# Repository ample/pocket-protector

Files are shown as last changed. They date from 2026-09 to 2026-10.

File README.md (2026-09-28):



Pocket Protector is a privacy-first DIY push-button voice recorder with searchable, fully local memory. Press a button to record, and the audio is transcribed, indexed, and made queryable with a local LLM. Nothing leaves your network.

```
[Button] → ESP32-C3 → Raspberry Pi (records chunks) → recordings/<session>/ on Mac
                                                          │
                                   processor.py (polls every 5s)
                                   1. ffmpeg: concat + loudnorm → session.wav
                                   2. Whisper (MLX) + pyannote speakers → transcript.txt + segments.json
                                   3. Ollama embeddings → Chroma vector DB
                                                          │
                          ask.py "question" → top-6 retrieval → llama3.1:8b answer with citations
```

## Repo layout

The repo is organized by where the code runs.

| Directory | Runs on | What it does |
|---|---|---|
| [`controller/`](controller/) | ESP32-C3 | Button gestures, record/shutdown pulses to the Pi, PowerBoost power control |
| [`pi/`](pi/) | Raspberry Pi | Records chunked audio sessions and syncs them to the Mac |
| [`mac/`](mac/) | Mac (Apple Silicon) | Transcribes, indexes, and answers questions |
| [`hardware/`](hardware/) | 3D printer | Enclosure files and parts list |
| [`site/`](site/) | Any static host | Setup microsite: a step-by-step build guide |

Each directory has its own README with setup steps.

## Session format (Pi → Mac contract)

```
recordings/YYYYMMDD-HHMMSS/
├── chunk-HHMMSS-NN.wav   # ~1-minute chunks, written by the Pi
├── DONE                  # Pi: recording finished and synced
├── session.wav           # Mac: concatenated + normalized
├── transcript.txt        # Mac: full text
├── segments.json         # Mac: [{start, end, speaker, text}, ...]
├── TRANSCRIBED           # Mac: stage 1 complete
└── INDEXED               # Mac: stage 2 complete
```

If you change this format on one side, update the other.

## Privacy

`recordings/` and `chroma/` (which stores transcript text) are git-ignored and never committed. So are `.env` files. Put hostnames and credentials there, and commit only the `.env.example` templates.

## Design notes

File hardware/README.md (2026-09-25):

# Hardware

3D-printable parts, exported from Fusion as `.3mf`.

| File | Purpose |
|---|---|
| `enclosure.3mf` | Main enclosure |
| `plug_test.3mf` | Test print for plug fit |

## Parts

- Raspberry Pi (model: TODO)
- ESP32-C3 Super Mini
- PowerBoost board with FM5324HJ1 boost IC + battery
- INMP441 I2S MEMS microphone
- Momentary push button
- 2N2222 NPN transistor + 1 kΩ resistor

See [controller/README.md](../controller/README.md) for wiring.

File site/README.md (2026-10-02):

# Setup microsite

A static, five-page build guide for Pocket Protector: overview, hardware, Raspberry Pi, Mac, and record & ask. Plain HTML, one stylesheet and one small script for the mobile menu, with no build step.

| File | Page |
|---|---|
| `index.html` | Overview and how it works |
| `hardware.html` | 01 · Print, wire, and flash the controller |
| `pi.html` | 02 · Boot config, Tailscale, SSH, services |
| `mac.html` | 03 · Clone, models, pyannote unlock, processor |
| `use.html` | 04 · Gestures, session lifecycle, `ask.py`, troubleshooting |
| `assets/styles.css` | Shared styles and color tokens |
| `assets/nav.js` | Mobile menu toggle (the nav falls back to a scrolling row without it) |
| `assets/logo.png` | Wordmark |
| `assets/og-image.png` | 1200×630 social share image |

## Preview

```bash
python3 -m http.server 8000 --directory site
```

Then open http://localhost:8000.

## Deploy

Any static host works. Point it at `site/` with no build command.

## Keeping it accurate

The pages repeat facts from the device READMEs: pins, pulse timings, paths, and model names. If you change them in `controller/`, `pi/`, or `mac/`, update the matching page too.

Placeholders still to fill in:

- `[PI MODEL]` in `index.html` (the parts list)
- `[ADD MIC PIN MAP]` in `hardware.html` (Pi-side wiring)

## Share previews

Each page has Open Graph and Twitter card tags pointing at `https://pocket-protector.diy`. If the site moves to another domain, update the `canonical`, `og:url`, `og:image` and `twitter:image` URLs in every page.

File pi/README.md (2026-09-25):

# Pi (recorder)

The Raspberry Pi listens for control pulses from the [controller](../controller/), records audio in 1-minute chunks, and uploads finished sessions to the Mac over Tailscale.

## Layout

| Path | Contents |
|---|---|
| `recorder.py` | GPIO15 pulse listener; runs `arecord` in 1-minute chunks and writes `DONE` |
| `uploader.py` | rsyncs finished sessions to the Mac and writes a local `UPLOADED` marker |
| `systemd/` | Unit templates for both services (`__USER__` etc. are filled in by `install.sh`) |
| `config/config.txt.snippet` | The lines added to `/boot/firmware/config.txt` |
| `config/sudoers.d/recorder-shutdown` | Lets the recorder run `shutdown -h now` without a password |
| `install.sh` | Installs packages, the sudoers rule, and the services |
| `.env.example` | Template for the upload destination; copy to `.env` (git-ignored) |

## Hardware

- **Mic:** INMP441 I2S MEMS mic, driven by the `googlevoicehat-soundcard` overlay. It appears as ALSA card `sndrpigooglevoi`; check with `arecord -l`.
- **Control input:** physical pin 10 (BCM GPIO15), with an internal pull-up, receiving open-drain LOW pulses from the ESP32.
- **Recording LED:** BCM GPIO27.

| Pulse length | Meaning |
|---|---|
| 0.05–0.70 s (ESP32 sends ~150 ms) | Toggle recording |
| ≥0.90 s (ESP32 sends ~1200 ms) | Stop any recording, write `DONE`, then `shutdown -h now`. The ESP32 cuts power 15 s later. |

Pin 10 is also UART RX, which is why `config.txt` sets `enable_uart=0`. `cmdline.txt` must not contain `console=serial0,...`. A stock Bookworm install only uses `console=tty1`.

## Setup

1. **Boot config:** add the lines from [`config/config.txt.snippet`](config/config.txt.snippet) under `[all]` in `/boot/firmware/config.txt`, then reboot.
2. **Tailscale:** install and log in on both the Pi and the Mac.
3. **SSH to the Mac:** the uploader uses `ssh -o BatchMode=yes`, so it needs key auth.
   - On the Mac: System Settings → General → Sharing → turn on **Remote Login**.
   - On the Pi: `ssh-keygen -t ed25519` (if you don't have a key), then `ssh-copy-id <mac-user>@<mac-host>`.
   - Test with `ssh -o BatchMode=yes <mac-user>@<mac-host> true`.
4. **Configure:** `cp pi/.env.example pi/.env` and fill in the Mac user, host, and recordings path.
5. **Install:** from the repo clone on the Pi, run `./pi/install.sh`.

Logs: `journalctl -u recorder -u uploader -f`

## Output contract

Sessions are recorded to `~/recordings/` on the Pi:

```
~/recordings/YYYYMMDD-HHMMSS/   # named by the Pi's clock at record start
├── chunk-HHMMSS-01.wav         # arecord --max-file-time 60, 16 kHz mono S16_LE
├── chunk-HHMMSS-02.wav
├── DONE                        # written after arecord exits
└── UPLOADED                    # Pi-only; written after a successful upload
```

## Sync to the Mac

`uploader.py` polls every 5 s for sessions that have `DONE` but not `UPLOADED`. For each one, it:

1. rsyncs the audio, excluding the `DONE` and `UPLOADED` markers
2. rsyncs `DONE` on its own, **last**

The Mac's [processor](../mac/) therefore never sees `DONE` before all the audio has arrived. Failed uploads retry on the next pass.

## Known limitations

- Uploaded sessions are never deleted from the Pi, so the SD card will fill up over time.
- The Pi has no real-time clock. Sessions recorded before it syncs time over the network can get wrong timestamps in their names.

## Don't commit

SSH keys, Wi-Fi config (`wpa_supplicant.conf`, NetworkManager connections), Tailscale auth, and `pi/.env`.

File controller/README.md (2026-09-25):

# Controller (ESP32-C3)

An always-on ESP32-C3 Super Mini reads one momentary button. It tells the Pi to start or stop recording and to shut down, and it switches the PowerBoost's 5V output on and off.

## Gestures

| Gesture | Action |
|---|---|
| Single click | 150 ms LOW pulse to the Pi: toggle recording |
| Double click | Unused |
| Triple click | Tap the PowerBoost K pin: power the Pi on |
| Long press (≥2.5 s, fires on release) | 1200 ms pulse to the Pi (shutdown), wait 15 s, double-tap K to cut 5V |

The Pi distinguishes record and shutdown requests by pulse length.

## Wiring

| ESP32 pin | Connects to |
|---|---|
| GPIO 4 | Momentary button → GND (internal pull-up) |
| GPIO 5 | 1 kΩ → base of a 2N2222 that pulls the PowerBoost K pin to ground |
| GPIO 3 | Raspberry Pi physical pin 10 (GPIO15), open-drain |
| GND | Common ground |

GPIO 3 is open-drain so the ESP32 never drives voltage into a powered-off Pi. The Pi's pull-up holds the line high.

## Flashing

1. Open `esp32_controller/esp32_controller.ino` in the Arduino IDE. The folder name must match the sketch name.
2. Board: **ESP32C3 Dev Module** (esp32 core by Espressif). Enable *USB CDC On Boot* to get serial output.
3. Upload, then open Serial Monitor at 115200 baud to see gesture logs.

## Timing constants

All timings are `const`s at the top of the sketch: debounce, click window, long-press threshold, K tap/gap, pulse lengths, and the shutdown delay. The K timings match the FM5324HJ1 boost IC. There, one short press is a tap and a double press turns the output off.

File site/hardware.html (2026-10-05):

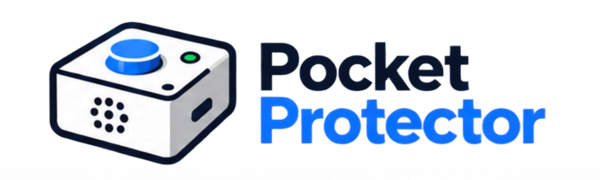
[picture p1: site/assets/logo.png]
Pocket Protector home
 Menu

STEP 01 OF 04

# Build the hardware

Print the case, make three connections to the ESP32, and flash the controller. When you're done, one button powers the Pi on, starts recordings and shuts everything down.

1.1 · PRINT

## Print the enclosure

Both parts are in hardware/, exported from Fusion as .3mf. Start with the small plug test. It tells you if the plug fits before you commit to the full case.

plug_test.3mf

First · checks plug fit

enclosure.3mf

Then · the main case

1.2 · WIRE

## Wire the controller

The ESP32-C3 stays on all the time. It reads the button, signals the Pi, and switches the PowerBoost's 5V output through a 2N2222.

Why open-drain?

GPIO 3 never drives voltage into a powered-off Pi. The Pi's pull-up holds the line high, and the ESP32 only pulls it low.

Power switching

The transistor "presses" the PowerBoost K pin. One tap turns 5V on, a double tap turns it off.

Pi-side wiring

INMP441 mic to the Pi's I2S pins, recording LED to BCM GPIO27. [ADD MIC PIN MAP]

1.3 · FLASH

## Flash the ESP32

1. Open controller/esp32_controller/esp32_controller.ino in the Arduino IDE. The folder name must match the sketch.
2. Board: ESP32C3 Dev Module (esp32 core by Espressif).
3. Turn on USB CDC On Boot for serial output.
4. Upload, then open the Serial Monitor at 115200 baud.

Tune the feel: debounce, click window, long-press threshold and pulse lengths are constants at the top of the sketch.

## Check: try every gesture

With the Serial Monitor open, each gesture should print a log line. The lower trace shows the signal the controller sends.

### Single click

Toggles recording on the Pi.

### Triple click

Powers the Pi on.

### Long press

Fires on release. Shuts the Pi down cleanly, then cuts power.

← Overview Next: Set up the Pi →

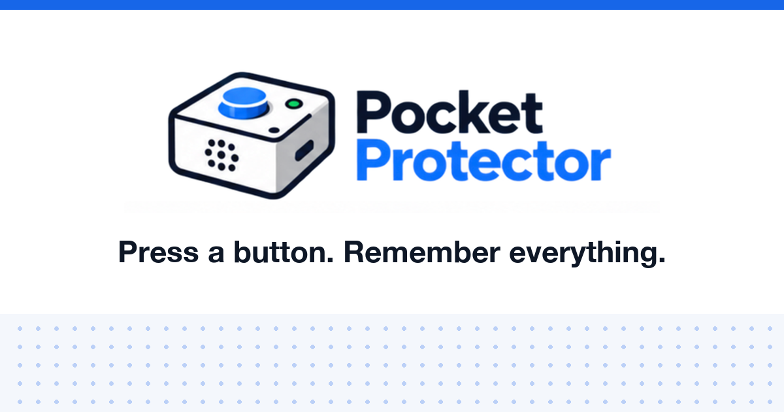
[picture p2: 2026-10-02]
site/assets/og-image.png

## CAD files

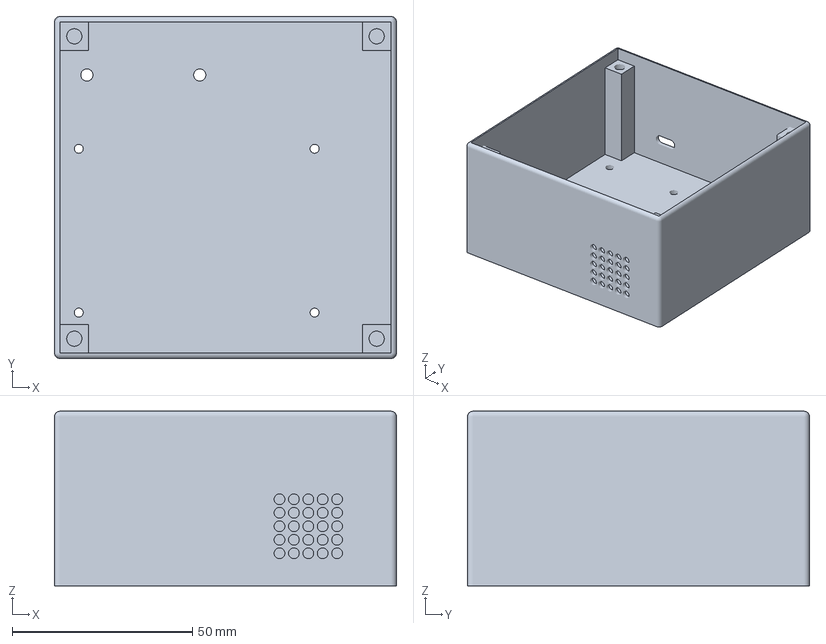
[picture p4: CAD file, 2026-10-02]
hardware/enclosure_base.3mf
95.0 x 95.0 x 48.5 mm

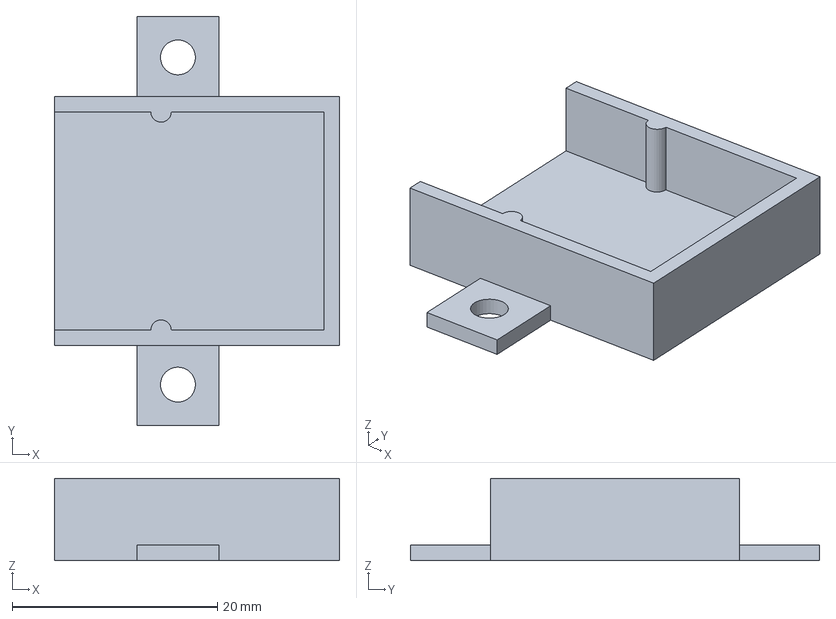
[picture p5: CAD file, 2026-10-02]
hardware/power_boost_sled.3mf
27.8 x 39.9 x 8.00 mm

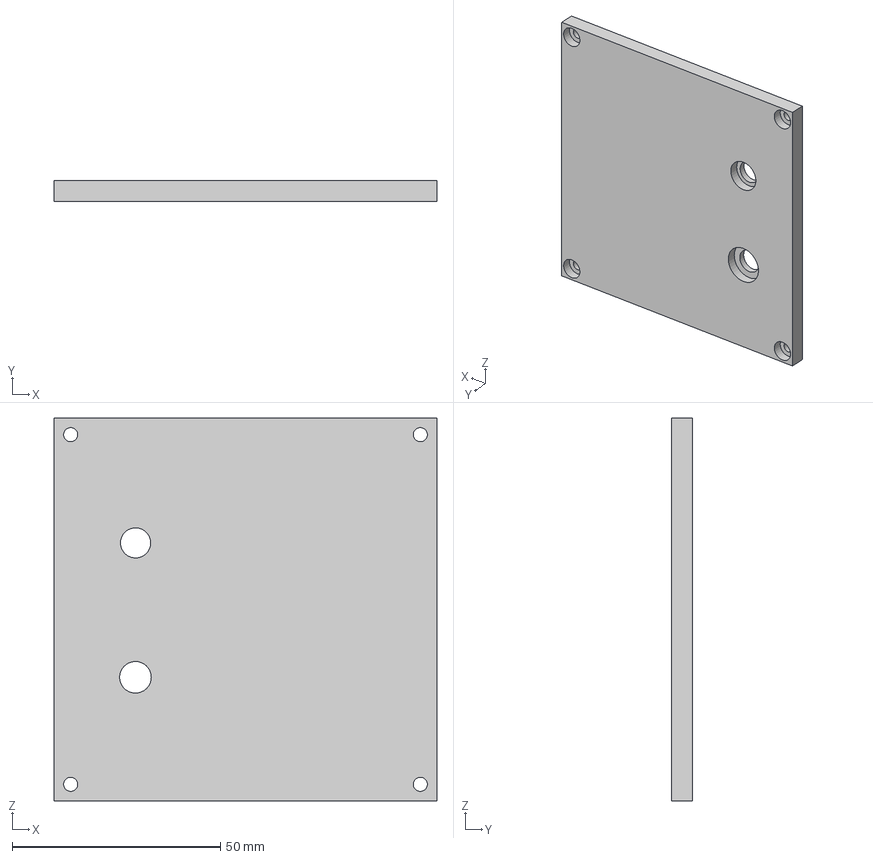
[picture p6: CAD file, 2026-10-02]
hardware/enclosure_lid.3mf
92.0 x 5.00 x 92.0 mm

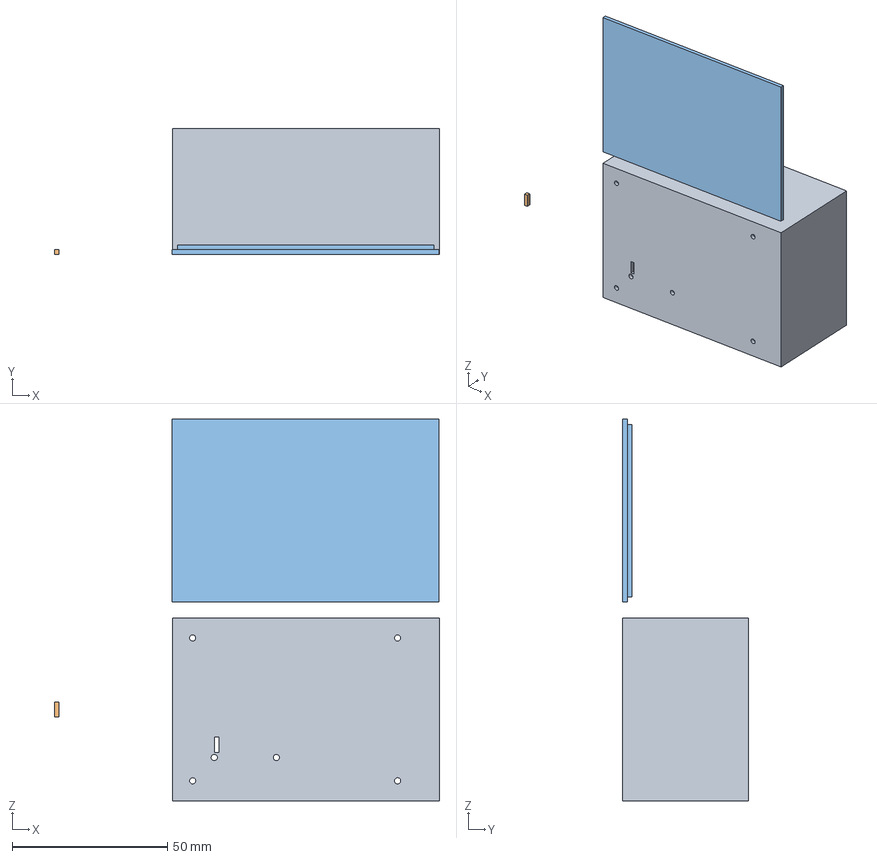
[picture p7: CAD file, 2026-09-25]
hardware/enclosure.3mf
124.0 x 40.5 x 123.0 mm

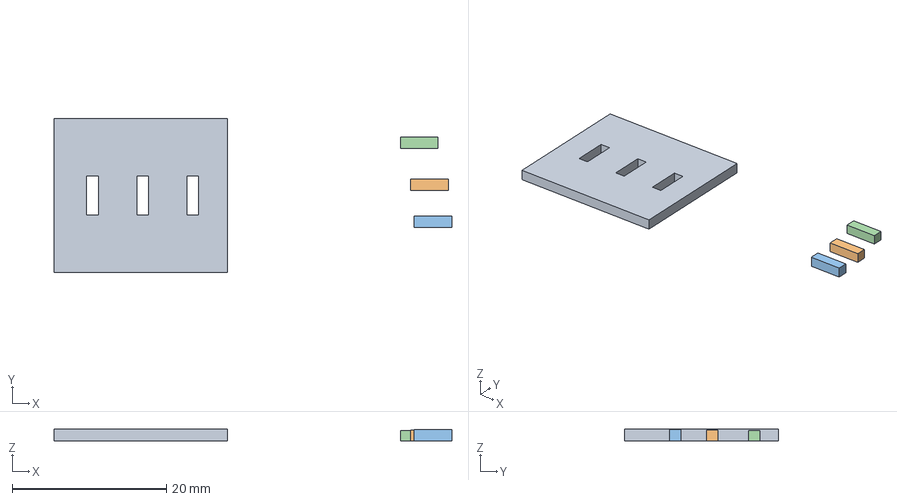
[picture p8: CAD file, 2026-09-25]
hardware/plug_test.3mf
51.7 x 20.0 x 1.50 mm

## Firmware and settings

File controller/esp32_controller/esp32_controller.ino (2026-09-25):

#include <Arduino.h>

// ESP32-C3 Super Mini -> Raspberry Pi recorder controller
//
// Wiring:
//   GPIO 4 -> momentary button -> common GND
//   GPIO 5 -> 1K resistor -> base of 2N2222 controlling PowerBoost K
//   GPIO 3 -> Raspberry Pi physical pin 10 (GPIO15)
//   ESP32 GND -> common ground
//
// Behavior:
//   Single click -> short LOW pulse to Pi = RECORD_TOGGLE
//   Triple click -> one K tap = turn PowerBoost/Pi on
//   Long press   -> tell Pi to shut down, wait, then DOUBLE-TAP K
//                   to turn the PowerBoost 5V output off
//
// GPIO3 is open-drain so the always-on ESP32 does NOT drive voltage
// into the Raspberry Pi while the Pi is powered off.

const int BUTTON_PIN = 4;
const int K_PIN = 5;
const int PI_SIGNAL_PIN = 3;

const unsigned long DEBOUNCE_MS = 40;
const unsigned long CLICK_WINDOW_MS = 600;
const unsigned long LONG_PRESS_MS = 2500;

// K-button timing
// The FM5324HJ1 recognizes a short press as a tap and a double press
// as "turn boost output off."
const unsigned long K_TAP_MS = 100;
const unsigned long K_DOUBLE_GAP_MS = 150;

// Pulse lengths sent to Raspberry Pi
const unsigned long RECORD_PULSE_MS = 150;
const unsigned long SHUTDOWN_PULSE_MS = 1200;

// Give Linux time to finish shutting down before removing 5V.
const unsigned long SHUTDOWN_CUT_DELAY_MS = 15000;

bool buttonWasDown = false;
unsigned long buttonDownAt = 0;

int clickCount = 0;
unsigned long lastClickAt = 0;


void setKPressed(bool pressed) {
  // GPIO5 HIGH turns on the NPN transistor,
  // which pulls the PowerBoost K pin to common ground.
  digitalWrite(K_PIN, pressed ? HIGH : LOW);
}


void tapK() {
  Serial.println("Tapping PowerBoost K...");

  setKPressed(true);
  delay(K_TAP_MS);
  setKPressed(false);

  Serial.println("K tap complete.");
}


void doubleTapK() {
  Serial.println("Double-tapping PowerBoost K to turn 5V off...");

  setKPressed(true);
  delay(K_TAP_MS);
  setKPressed(false);

  delay(K_DOUBLE_GAP_MS);

  setKPressed(true);
  delay(K_TAP_MS);
  setKPressed(false);

  Serial.println("K double-tap complete.");
}


void signalPi(unsigned long pulseLengthMs) {
  // Open-drain line: LOW actively pulls the Pi input to ground.
  // HIGH releases the line so the Pi's own pull-up holds it high.
  digitalWrite(PI_SIGNAL_PIN, LOW);
  delay(pulseLengthMs);
  digitalWrite(PI_SIGNAL_PIN, HIGH);
}


void shutdownPiAndCutPower() {
  Serial.println("Sending shutdown request to Pi...");
  signalPi(SHUTDOWN_PULSE_MS);

  Serial.println("Waiting for Raspberry Pi to shut down...");
  delay(SHUTDOWN_CUT_DELAY_MS);

  // FM5324HJ1: double press on K disables boost output.
  doubleTapK();
}


void setup() {
  Serial.begin(115200);

  pinMode(BUTTON_PIN, INPUT_PULLUP);

  pinMode(K_PIN, OUTPUT);
  setKPressed(false);

  pinMode(PI_SIGNAL_PIN, OUTPUT_OPEN_DRAIN);
  digitalWrite(PI_SIGNAL_PIN, HIGH);  // release line

  delay(300);

  Serial.println();
  Serial.println("ESP32 recorder controller started.");
  Serial.println("Single click = record toggle");
  Serial.println("Triple click = PowerBoost ON");
  Serial.println("Long press   = shutdown Pi, then PowerBoost OFF");
}


void loop() {
  bool buttonDown = (digitalRead(BUTTON_PIN) == LOW);

  if (buttonDown && !buttonWasDown) {
    buttonDownAt = millis();
    buttonWasDown = true;
    delay(DEBOUNCE_MS);
  }

  if (!buttonDown && buttonWasDown) {
    unsigned long pressLength = millis() - buttonDownAt;
    buttonWasDown = false;

    if (pressLength >= LONG_PRESS_MS) {
      clickCount = 0;

      Serial.println("LONG PRESS detected.");
      shutdownPiAndCutPower();
    } else {
      clickCount++;
      lastClickAt = millis();
    }

    delay(DEBOUNCE_MS);
  }

  if (clickCount > 0 &&
      millis() - lastClickAt > CLICK_WINDOW_MS) {

    if (clickCount == 1) {
      Serial.println("SINGLE CLICK detected.");
      Serial.println("Sending record-toggle pulse to Pi...");
      signalPi(RECORD_PULSE_MS);
    }
    else if (clickCount == 2) {
      Serial.println("DOUBLE CLICK detected.");
      // Intentionally unused.
    }
    else if (clickCount >= 3) {
      Serial.println("TRIPLE CLICK detected.");
      tapK();
    }

    clickCount = 0;
  }
}

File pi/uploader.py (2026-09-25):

#!/usr/bin/env python3
"""Pocket uploader: ships finished recording sessions to the Mac Mini over Tailscale.

Watches ~/recordings/ for session folders containing a DONE marker and
rsyncs them to DEST. Audio chunks ship first; the DONE marker ships last,
so the Mac never sees a session marked complete before all audio arrived.
Writes a local UPLOADED marker on success. Safe to re-run: uploaded
sessions are skipped, failed sessions retry on the next pass.
"""

import os
import subprocess
import time
from pathlib import Path

# Set in pi/.env (loaded by uploader.service via EnvironmentFile).
DEST = f"{os.environ['MAC_USER']}@{os.environ['MAC_HOST']}:{os.environ['MAC_RECORDINGS_DIR']}"

RECORDINGS_DIR = Path.home() / "recordings"
POLL_SECONDS = 5


def rsync(*args: str) -> None:
    subprocess.run(
        ["rsync", "-a", "--partial", "-e", "ssh -o BatchMode=yes", *args],
        check=True,
        capture_output=True,
        text=True,
    )


def upload_session(session: Path) -> None:
    remote = f"{DEST}/{session.name}/"
    # 1) ship the audio
    rsync("--exclude", "DONE", "--exclude", "UPLOADED", f"{session}/", remote)
    # 2) ship the DONE marker last = arrival receipt for the Mac side
    rsync(str(session / "DONE"), remote)
    (session / "UPLOADED").touch()
    n = len(list(session.glob("chunk-*.wav")))
    print(f"UP  {session.name} ({n} chunks) -> {remote}", flush=True)


def main() -> None:
    print(f"Watching {RECORDINGS_DIR} -> {DEST}", flush=True)
    while True:
        if RECORDINGS_DIR.exists():
            for session in sorted(RECORDINGS_DIR.iterdir()):
                if not session.is_dir():
                    continue
                if (session / "DONE").exists() and not (session / "UPLOADED").exists():
                    try:
                        upload_session(session)
                    except subprocess.CalledProcessError as exc:
                        detail = exc.stderr.strip() if exc.stderr else exc
                        print(f"ERROR {session.name}: rsync failed: {detail} (will retry)", flush=True)
                    except Exception as exc:
                        print(f"ERROR {session.name}: {exc} (will retry)", flush=True)
        time.sleep(POLL_SECONDS)


if __name__ == "__main__":
    main()

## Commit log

2026-09-25 Initial commit: ESP32 recorder controller, local transcribe/index pipeline, and ask CLI
    [enclosure.3mf, plug_test.3mf]
2026-09-25 Restructure repo by device: controller/, pi/, mac/, hardware/
    Move ESP32 sketch to controller/, processing scripts to mac/, and
    enclosure files to hardware/. Scaffold pi/ with README, output
    contract, and .env.example. Add per-directory READMEs.
    [enclosure.3mf, plug_test.3mf]
2026-10-01 📌 fix: pin torch and torchaudio to 2.8.0 for pyannote 3.x
2026-10-01 ♻️ refactor: resolve recordings and chroma paths from the project root
2026-10-01 🚩 feat: add SKIP_INDEXING to run transcription without Ollama or Chroma
2026-10-02 💄 feat: use the recorder box icon as the site favicon
2026-10-02 ✨ feat: mobile menu, white nav CTA text and Open Graph tags
2026-10-02 Update CAD files
    [enclosure_base.3mf, enclosure_lid.3mf, power_boost_sled.3mf]
2026-10-02 🔧 fix: point canonical and share URLs at pocket-protector.diy
2026-10-05 📈 feat: add Google Analytics tag to all site pages
